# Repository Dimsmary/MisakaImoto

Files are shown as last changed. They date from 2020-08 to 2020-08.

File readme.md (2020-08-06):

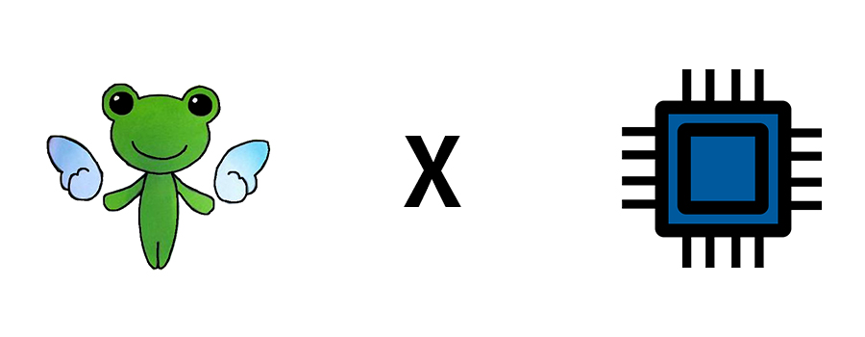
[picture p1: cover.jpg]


# 御坂妹妹护目镜 X Raspberry Pi

嗨，这是一个基于树莓派的硬核ACG周边制作的项目。其原型是《某科学的超电磁炮》中 *御坂美琴* 的克隆体： *御坂妹妹* 所佩戴的战术护目镜。

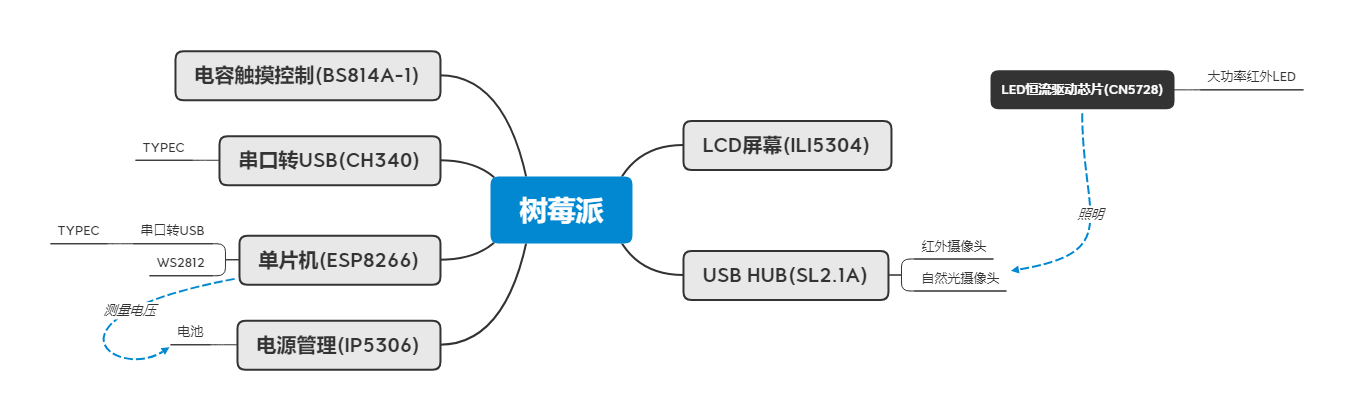
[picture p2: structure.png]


本项目在实现还原其外形后还添加了以下功能：

- 夜视
- 人脸探测
- 边缘捕捉
- 录像
- 画面放大

暂时的，功能比较简单。但依赖于树莓派强大的性能，我计划继续在其上添加功能，目前计划添加：

- 人脸识别（可以识别出你是谁）
- 物品识别
- OCR

现阶段为第一次可用的版本，后续改动说明将会更新在本文档末尾。

*有疑惑的地方欢迎提交issue

# 源文件结构

**3DModel**：Solidworks绘制的模型，以及用于3D打印的stl文件。

**Esp8266**：esp8266的Arduino代码

**Raspberrypi**：树莓派的C++程序代码

**python_demo**：初代开发的python代码，与C++功能基本相同。本项目起初采用python开发，后因python的执行效率问题将项目语言改为C++。python代码仅供参考使用。

**PCB**：原理图、Gerber、PCB布局（立创EDA格式）

# 硬件组成

这是主要部分的组成图表。

在本项目中包括了原理图和PCB布局，详细BOM可参见原理图。

*注意，在PCB布局中，ESP8266的GPIO15需要下拉至GND，否则无法正常烧录Arduino程序。在PCB中我忘了画，你可以自行改动或在PCB打板后手动连接。*

## 树莓派

这里树莓派与主板的连接方式为排针连接，可以使用0系列和Model A系列的树莓派。

本项目尝试过使用Raspberry Pi Zero w 和 3A+。

GPIO分配：

BCM 2/3 : 电压数据传输

BCM 17/27/22/10/9/11/8 : LCD显示屏数据传输

BCM 6 : 树莓派工作状态指示

BCM 13/19/26/21 : 触摸按键输入

BCM 20 : 装饰LED开关

BCM 14/15 : 串口通信

## ESP8266

在本项目中，ESP8266作为单片机为树莓派提供电池电压的测量和WS2812的控制。

注意，在PCB布局中，ESP8266的GPIO15需要下拉至GND，否则无法正常烧录Arduino程序。在PCB中我忘了画，你可以自行改动或在PCB打板后手动连接。

其余外围电路均为ESP8266的最小系统电路。

GPIO分配：

GPIO 14/12 : 电压数据传输

ADC : 测量电压

GPIO 2 : 树莓派工作状态指示

GPIO 13 : WS2812控制

## 其余外围芯片

外围芯片电路均按照芯片手册绘制。

## PCB跳线设置

在PCB上我设置了零欧条线，用于开关各个部分的供电。

J_VIN : IP5306的充电跳线，去除后连接USB1将不会对电池充电。

J_5V : IP5306的输出跳线，去除后电池将不会对整个系统供电。

RPI_USB5VIN : USB2的5V供电，在断开J_5V后，可以连接该跳线使用USB2对整个系统供电。

J_WS2812_PWR : WS2812供电

# 软件设计

在树莓派端，采用OpenCV 和 C++ 进行开发，在ESP8266上采用Arduino进行开发。

## 树莓派端

树莓派用到的库：Wiring Pi/Boost/Open CV(3.9.4)

程序执行流程：

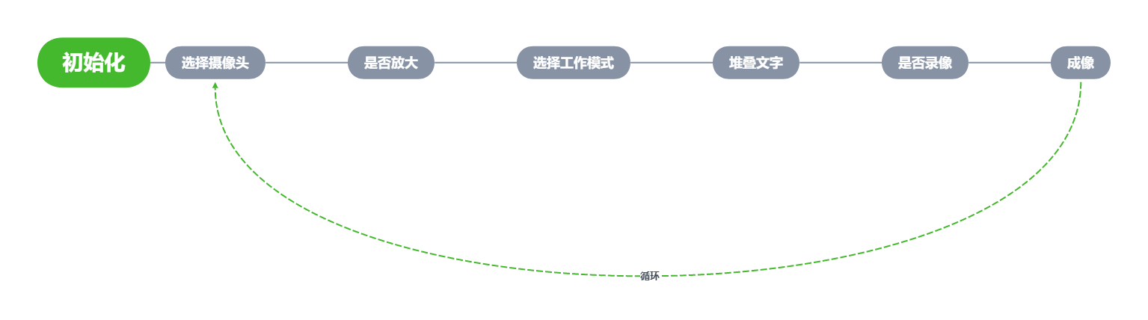
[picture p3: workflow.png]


**gpio_status**

其中，所有选择信息都被存放在了gpio_status的对象中。

此外，该对象还负责处理触摸芯片传来的电平信号并进行处理：

使用Wiring Pi库配置触摸芯片对应的引脚为下降沿中断，在发生中断时调用在main中绑定的函数进行处理。

**fb-pusher**

该对象负责将OpenCV生成的图像推至/dev/fb*，即Framebuffer。

参考自https://stackoverflow.com/questions/32709175/writing-to-dev-fb0-using-opencv

**voltage_detect**

该对象负责接收单片机传输的电压数据，传输协议是自行编写的一个非常简陋的协议：

在连续传输12个低电平后，确认数据开始传输。

首先传输四位二进制数，表示个位。

其次传输两组四位二进制数分别表示小数点后第一位和后第二位。

这三组二进制数表示出电压的数值。

**video_player**

负责开机动画的播放

**frame_stacker**

负责文字的堆叠

## ESP8266

ESP8266主要负责两件事：电池电压的探测和树莓派工作状态的指示。

在上电时，signal(BCM6-GPIO2)将被上拉，呈高电平状态，表示树莓派未启动。

此时ESP8266将控制WS2812来向用户示意。

在树莓派启动完成后，将会拉低signal(BCM6-GPIO2)，表示树莓派启动完成，ESP8266将关闭WS2812并开始向树莓派传输电压数据。

# 3D模型

3D模型采用SolidWorks绘制 没啥好说的

# 零零碎碎

1）电容触摸芯片的按键去抖不太行，不建议用这款芯片。

2）TYPEC的母座还是卖贵点的好，我买的七毛钱一个的母座到现在插拔已经非常松了。

# 更新

2020/08/05 初版完成

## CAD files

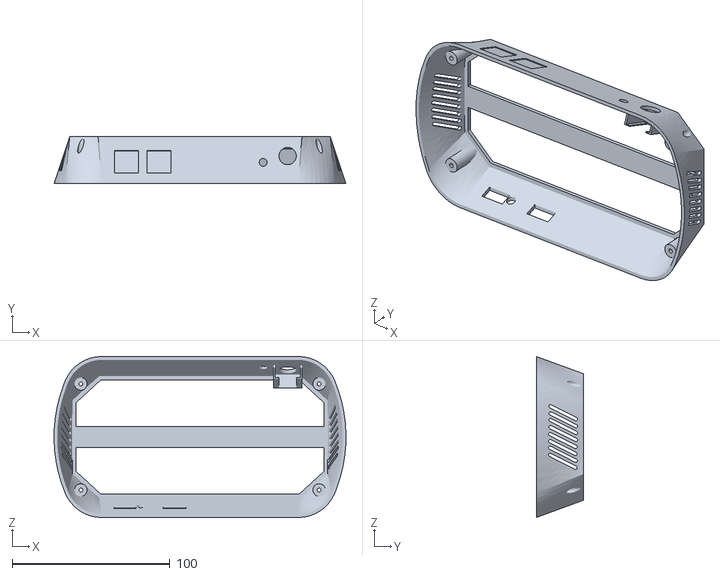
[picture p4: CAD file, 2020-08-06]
3Dmodle/3Dmodel_release_1.3.STL
185.0 x 30.0 x 102.0

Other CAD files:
3Dmodle/3Dmodel_release.SLDPRT

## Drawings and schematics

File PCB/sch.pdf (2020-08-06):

GND A1B12 VBUS A4B9 CC1 A5 DP1 A6 DN1 A7 SBU1 A8 CC2 B5 DP2 B6 DN2 B7 SBU2 B8 VBUS B4A9 GND B1A12 SHELL 1

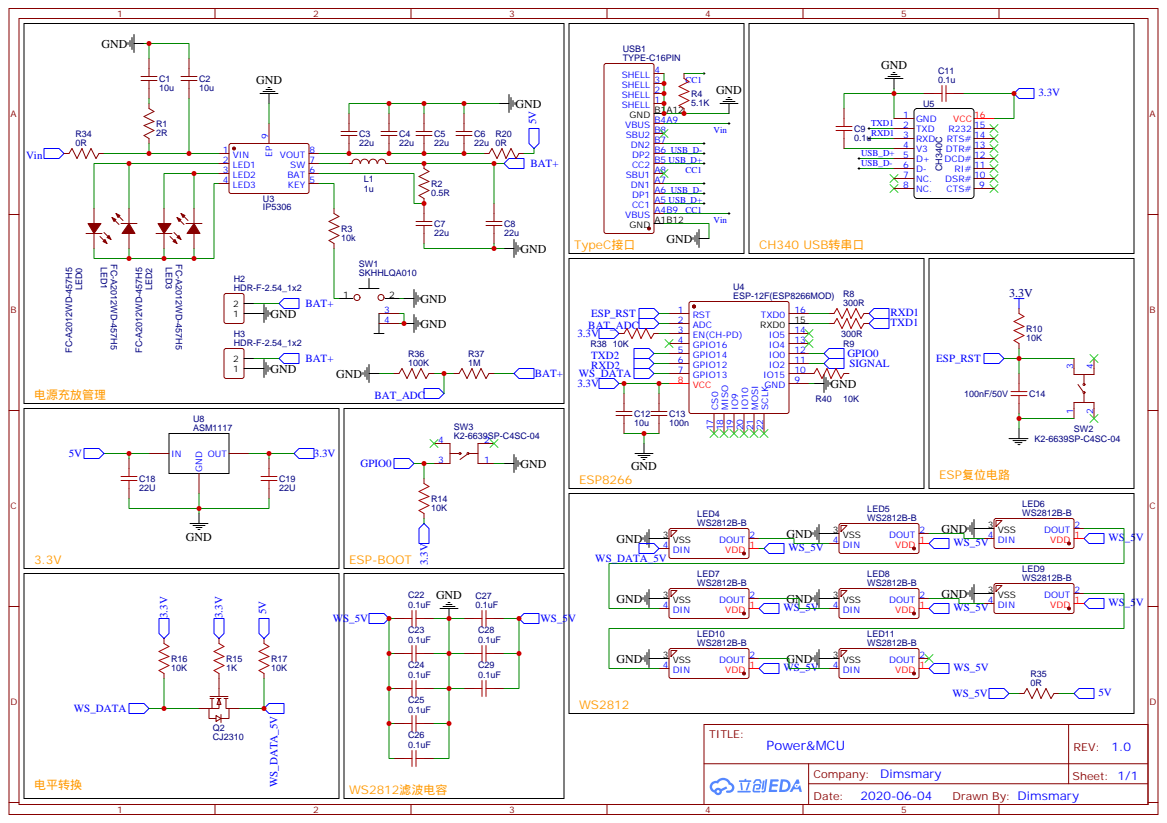
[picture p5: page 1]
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

## USB-HUB电容

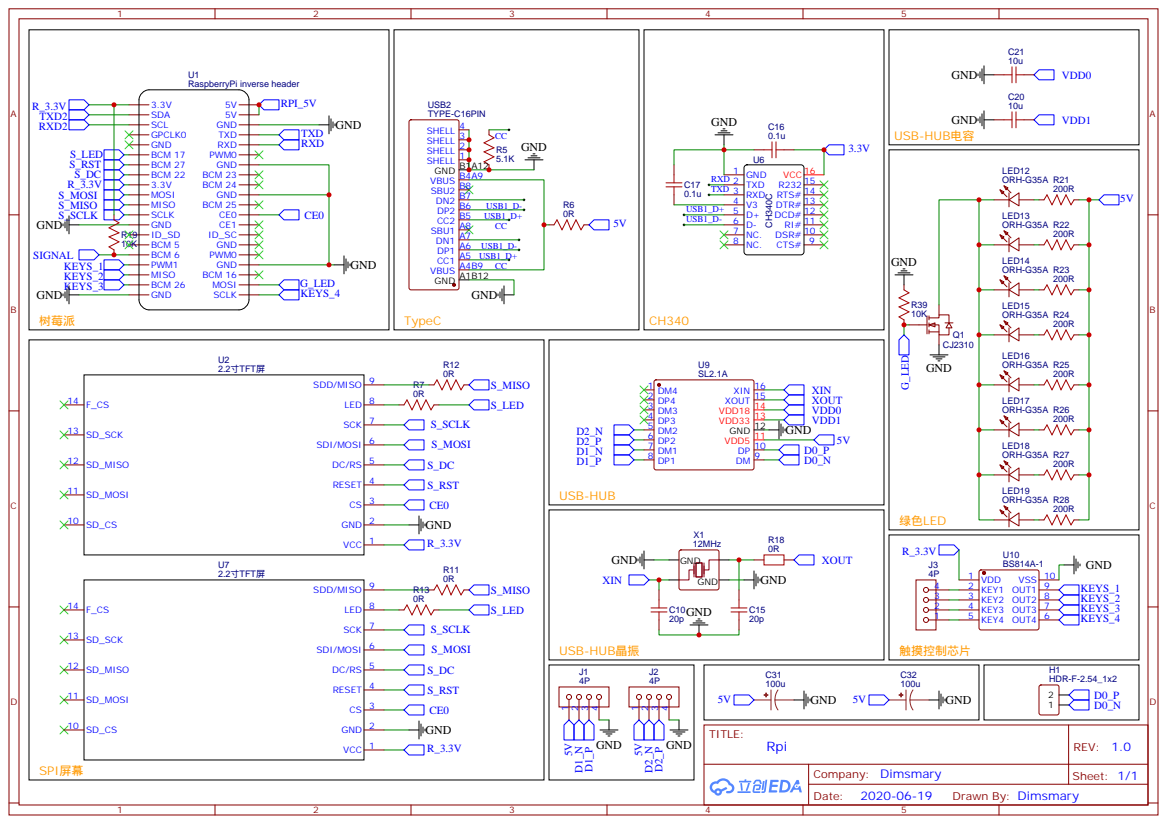
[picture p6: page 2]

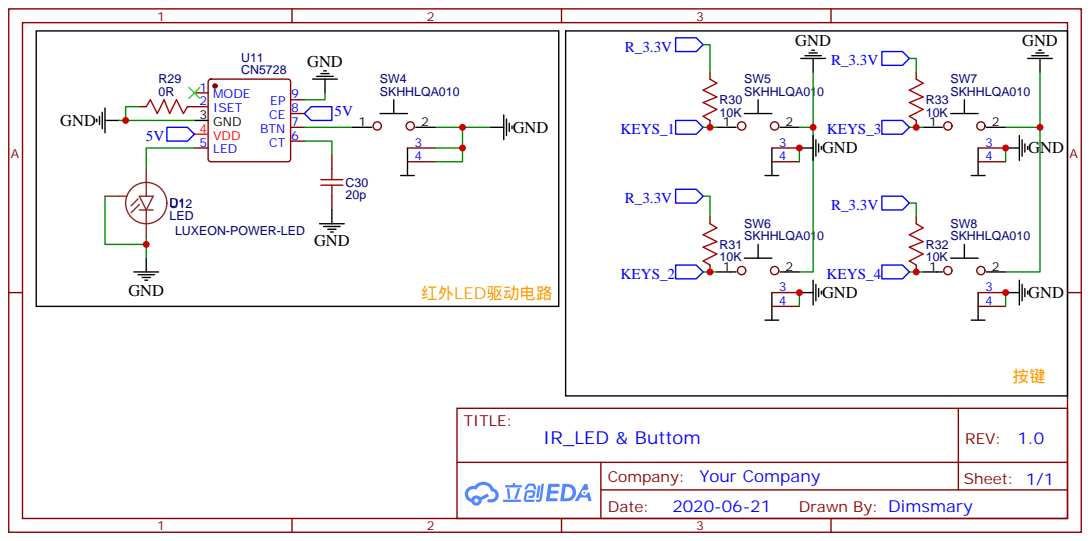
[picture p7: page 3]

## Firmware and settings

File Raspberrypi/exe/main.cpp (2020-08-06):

// C++标准库
#include <iostream>

// 其他库
#define BOOST_NO_CXX11_SCOPED_ENUMS
#include <boost/filesystem.hpp>
#undef BOOST_NO_CXX11_SCOPED_ENUMS
#include <boost/lambda/bind.hpp>

// 个人编写的库
#include <fb-pusher.hpp>
#include <gpio_status.hpp>
#include <video_player.hpp>
#include <frame_stacker.hpp>
#include <voltage_detect.hpp>

// opencv 基本库
#include <opencv2/opencv.hpp>

// opencv 人脸识别需要的库
#include "opencv2/objdetect/objdetect.hpp"
#include "opencv2/highgui/highgui.hpp"
#include "opencv2/imgproc/imgproc.hpp"

// 树莓派基于WiringPi库的引脚定义
#define KEY0 23
#define KEY1 24
#define KEY2 25
#define KEY3 29
#define LED 28
#define SIGNAL 22

#define SDA 8
#define SCL 9

// namespace
using namespace cv;
using namespace std;
using namespace boost::filesystem;
using namespace boost::lambda;

// 创建GPIO扫描对象
gpio_status gpio(KEY0, KEY1, KEY2, KEY3, LED, SIGNAL);

// 创建ADC数据传输处理对象
voltage_detect adc(SDA, SCL);

// 加载人脸识别模型
CascadeClassifier face_cascade;

// 创建文本叠对象
frame_stacker stacker1;
frame_stacker stacker2;


// 创建中断处理函数
void gpioInterrupt0(){
    gpio.gpioInterrupt(0);

    // 显示提示文本
    if(gpio.get_menu()){
        // 菜单B下的开关指示灯
        if(gpio.return_led()){
            stacker1.fill_text("Light ON");
        }
        else{
            stacker1.fill_text("LIGHT OFF");
        }
    }else{
        // 菜单A下的切换摄像头
        if(gpio.get_camera()){
            stacker1.fill_text("Camera IR");
        }else{
            stacker1.fill_text("Camera NORM");
        }
    }
    stacker1.fill_times(50);
}

void gpioInterrupt1(){
    gpio.gpioInterrupt(1);
    if(gpio.get_menu()){
    }else{
        if(gpio.get_zoom()){
            stacker1.fill_text("Zoom 2X");
        }else{
            stacker1.fill_text("Zoom 1X");
        }
    }
    stacker1.fill_times(50);
}

void gpioInterrupt2(){
    gpio.gpioInterrupt(2);
    if(gpio.get_menu()){
        if(gpio.get_rec()){
            stacker1.fill_text("REC Begin");
        }else{
            stacker1.fill_text("REC End");
        }

    }else{
        switch(gpio.get_status()){
            case 0:
                stacker1.fill_text("Normal Mode");
                break;
            case 1:
                stacker1.fill_text("Gray Scale");
                break;
            case 2:
                stacker1.fill_text("Canny");
                break;
            case 3:
                stacker1.fill_text("Face Detect");
                break;
        }
    }
    stacker1.fill_times(50);
}

void gpioInterrupt3(){
    gpio.gpioInterrupt(3);
    if(gpio.get_menu()){
        stacker1.fill_text("Menu B");
        stacker1.fill_times(50);
    }else{
        stacker1.fill_text("Menu A");
        stacker1.fill_times(50);
    }

}

void gpioInterrupt_adc(){
    adc.data_process();
    // 获取电压
    string vol = to_string(adc.get_voltage());

    // 字符串处理
    vol = vol.substr(0, 4);
    vol = vol + "V";

    // 显示电压
    stacker2.fill_text(vol);
    stacker2.fill_times(1000);
}


// ==================主函数================ //
int main(){

    // 初始化文字堆叠对象

    stacker1.fill_text("Dimsmary");
    stacker1.fill_times(100);
    stacker1.set_fontscale(0.5);


    stacker2.set_origin(15);
    stacker2.set_color(0xff, 0xff, 0xff);
    stacker2.set_fontscale(0.5);

    // 创建framebuffer显示对象
    fb fb;

    // 绑定中断函数
    gpio.bind_internal_function(
            gpioInterrupt0,
            gpioInterrupt1,
            gpioInterrupt2,
            gpioInterrupt3);

    adc.bind_internal_function(gpioInterrupt_adc);

    // 创建摄像头对象
    VideoCapture cap0(0);
    VideoCapture cap1(2);
    // 创建图像容器
    Mat frame;
    Mat display;

    // 创建opencv功能对象
    Size dsize = Size(320, 240);    // 用于缩放图片
    Rect dcut(120, 160, 320, 240);  // 用于裁切图片

    // 绑定人脸识别模型
    face_cascade.load("haarcascade_frontalface_default.xml");

    // 示意单片机启动成功
    gpio.SIGNAL_UP();

    // 打印启动信息
    cout << "Main Process: Program Initialize Success." << endl;

    //开头动画
    {
        video_player vp;
        vp.video_play(fb);
    }


    while(true){

        // 切换摄像头
        if(gpio.get_camera()){
            cap1.read(frame);

        }else{
            cap0.read(frame);
        }

        // 切换放大状态
        if(gpio.get_zoom()){
            // 将原始图片进行裁切
            frame = frame(dcut);
        }else{
            // 将原始图像进行缩放
            resize(frame, frame, dsize);
        }

        // 切换工作模式
        int now_status = gpio.get_status();


        //==========此前图像的名称为frame==============//
        //==========模式切换==============//
        // 正常模式
        if(now_status == 0){
            display = frame;
        }

        // 灰度显示模式
        else if(now_status == 1){
            cvtColor(frame, frame, CV_BGR2GRAY);
            cvtColor(frame, display, CV_GRAY2BGR);
        }

        // 边缘检测模式
        else if(now_status == 2){
            Canny(frame, display, 100, 100);
            cvtColor(display, display, CV_GRAY2BGR);
        }
        else if(now_status == 3){
            std::vector<Rect> faces;
            face_cascade.detectMultiScale( frame, faces, 1.1, 2, 0|CV_HAAR_SCALE_IMAGE, Size(30, 30) );
            for( int i = 0; i < faces.size(); i++ )
            {
                Point center( faces[i].x + faces[i].width*0.5, faces[i].y + faces[i].height*0.5 );
                ellipse( frame, center, Size( faces[i].width*0.5, faces[i].height*0.5), 0, 0, 360, Scalar( 255, 0, 255 ), 4, 8, 0 );
            }
            display = frame;
        }



        //==========堆叠文字==============//
        stacker1.stack(display);
        stacker2.stack(display);

        // 录像
        if(gpio.get_rec()){

            // 存储路径
            path the_path( "rec" );

            // 获取文件个数
            int cnt = std::count_if(
                    directory_iterator(the_path),
                    directory_iterator(),
                    static_cast<bool(*)(const path&)>(is_regular_file) );

            // 生成文件名
            string cnt_str = to_string(cnt);
            string save_name = "rec/" + cnt_str + ".jpg";

            // 保存图片
            imwrite(save_name, display);

            cout << "Image Saved :" << save_name << endl;
        }


        // 推送至Framebufer
        fb.push_frame(display);
    }

    return 0;
}

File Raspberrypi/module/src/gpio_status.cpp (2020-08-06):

//
// Created by 79937 on 2020/7/28.
//

#include <wiringPi.h>
#include "gpio_status.hpp"
#include <iostream>



using namespace std;


void gpio_status::print() {
    cout << "wdnmd" << endl;
}


// 对象构造函数
gpio_status::gpio_status(int gpio0, int gpio1, int gpio2, int gpio3, int led, int signal) {

    wiringPiSetup();

    // GPIO编号赋值到数组
    gpio_list[0] = gpio0;
    gpio_list[1] = gpio1;
    gpio_list[2] = gpio2;
    gpio_list[3] = gpio3;
    LED = led;
    SIGNAL = signal;
    if_rec = false;


    // 初始化GPIO
    for(int i = 0; i < 3 ; i++ ){
        pinMode(gpio_list[i], INPUT);
    }

    // 初始化其他端口
    pinMode(LED, OUTPUT);
    pinMode(SIGNAL, OUTPUT);
}

// 绑定中断函数
void gpio_status::bind_internal_function(
        void (*function0)(),
        void (*function1)(),
        void (*function2)(),
        void (*function3)()
        ) {
    // 绑定中断函数，设置下降沿触发
    wiringPiISR (gpio_list[0], INT_EDGE_FALLING, function0) ;
    wiringPiISR (gpio_list[1], INT_EDGE_FALLING, function1) ;
    wiringPiISR (gpio_list[2], INT_EDGE_FALLING, function2) ;
    wiringPiISR (gpio_list[3], INT_EDGE_FALLING, function3) ;

}

void gpio_status::toggle(int port) {
    if(status_list[port]) {
        status_list[port] = 0;
    }else{
        status_list[port] = 1;
    }
}

// 中断处理函数
void gpio_status::gpioInterrupt(int port) {

    cout << "TouchPad: Detected port:" << port << endl;

    // 如果处于菜单A
    if(status_list[3] == 0){
        // 切换工作模式
        if(port == 2){
            if(status_list[port] == work_mode) {
                status_list[port] = 0;
            }
            else{
                status_list[port] ++;
            }
        }

        // 切换放大倍数、摄像头
        else{
            toggle(port);
        }
    }

    // 如果处于菜单B
    else{
        switch(port){
            // 翻转LED
            case 0:
                LED_toggle();
                break;
            // 关机
            case 1:
                system("shutdown -P now");
                break;
            // 录像
            case 2:
                if_rec = !if_rec;
                break;
            // 翻转菜单
            case 3:
                toggle(port);
                break;
        }

    }
}

// 返回状态列表值
int gpio_status::get_camera() {
    return status_list[0];
}

// 返回放大状态
int gpio_status::get_zoom() {
    return status_list[1];
}

// 返回工作模式
int gpio_status::get_status() {
    return status_list[2];
}

// 返回菜单
int gpio_status::get_menu() {
    return status_list[3];
}


// 激活signal
void gpio_status::SIGNAL_UP() {
    digitalWrite(SIGNAL, LOW);
}

// 释放signal
void gpio_status::SIGNAL_DOWN() {
    digitalWrite(SIGNAL, HIGH);
}

// 翻转LED
void gpio_status::LED_toggle() {
    if(digitalRead(LED)){
        digitalWrite(LED, LOW);
    }
    else{
        digitalWrite(LED, HIGH);
    }
}

int gpio_status::return_led() {
    return digitalRead(LED);
}

bool gpio_status::get_rec(){
    return if_rec;
}

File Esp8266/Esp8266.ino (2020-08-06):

#include <Adafruit_NeoPixel.h>


// 设定WS2812数据传输脚和灯珠数量
#define LED_PIN 13
#define LED_NUM 8

// 设定ADC引脚
#define ADC_PIN A0

#define SIGNAL_PIN 2
#define SDA_PIN 14
#define SCL_PIN 12

// ADC 数值矫正
#define BIAS -1
//#define BIAS 0.25

// ADC 各个位数存放
int L1 = 0;
int R1 = 0;
int R2 = 0;

// 


// WS2812传输对象
Adafruit_NeoPixel pixels(LED_NUM, LED_PIN, NEO_GRB + NEO_KHZ800);

// ADC数值
float batVoltage = 0;
int sensorValue = 0;  // value read from the pot


// WS2812测试函数
void light_up(){
     pixels.clear();
    for(int i=0; i<LED_NUM; i++) { // For each pixel...
    pixels.setPixelColor(i, pixels.Color(15, 15, 15));
    pixels.show();   // Send the updated pixel colors to the hardware.
    }
}

void light_down(){
    pixels.clear();
    for(int i=0; i<LED_NUM; i++) { // For each pixel...
    pixels.setPixelColor(i, pixels.Color(0, 0, 0));
    pixels.show();   // Send the updated pixel colors to the hardware.
    }
}


// 创建一个下降沿
void clock_pulse(){
  delay(10);
  digitalWrite(SCL_PIN, HIGH);
  digitalWrite(SCL_PIN, LOW);
  delay(10);
  digitalWrite(SCL_PIN, HIGH);
  delay(10);
}

// 负责数据传输
void data_transfer(int data){
  for(int i = 3; i > -1; i--){
    int load = 0;
    load = (data >> i) & 1;
    if(load){
      digitalWrite(SDA_PIN, HIGH);
    }
    else{
      digitalWrite(SDA_PIN, LOW);
    }
    clock_pulse();
  }
}

// 电压数据传输
void voltage_transfer(){

  // 传输开始的头码
  for(int i = 0; i < 12; i ++){
    digitalWrite(SDA_PIN, LOW);
    clock_pulse();
  }
  Serial.println("12 HEAD OVER");
  // 开始传输数据
  data_transfer(L1);
  data_transfer(R1);
  data_transfer(R2);
}

void update_voltage(){
  // 电压检测
  sensorValue = analogRead(ADC_PIN);
  batVoltage = (sensorValue / 1024.0) * 11 -BIAS;

  L1 = batVoltage;
  R1 = (batVoltage - L1) * 10;
  R2 = ((batVoltage - L1) - R1 / 10.0) * 100;
  
  Serial.println(batVoltage);
  
}

void setup() {
  // 初始化WS2812库
  pixels.begin();

  // 初始化串口
  Serial.begin(115200);

  // 初始化IO
  pinMode(SIGNAL_PIN, INPUT);
  pinMode(SDA_PIN, OUTPUT);
  pinMode(SCL_PIN, OUTPUT);
  digitalWrite(SDA_PIN, HIGH);
  digitalWrite(SCL_PIN, HIGH);


}

void loop() {
  delay(1000);

  // 如果树莓派仍然未启动
  if(digitalRead(SIGNAL_PIN)){
    light_up();
  }
  else{
    update_voltage();
    if(batVoltage > 1){
    voltage_transfer();
    }
    light_down();
  }

}
